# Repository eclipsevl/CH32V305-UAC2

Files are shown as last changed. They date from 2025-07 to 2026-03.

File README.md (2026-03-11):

# CH32V305-UAC2
a usb-hs uac2 dac

> [!NOTE]
> ch32v305fbp6 doesn't have OTG-HS(but it has OTG-FS), so you can't connect this project to a smartphone.  

## hardware v1
ch32v305fbp6 + es9018k2m + opa1678  

## hardware v2
ch32v305fbp6 + es9018k2m + opa1678 + sgm8262  
> [!NOTE]
> you may want to change all the 10uf capacity footprint to 0805, because 0603 10uf may only have 10v version  
> and you may want to add more capacity for charge pump  

## notice

Due to using inexpensive components, the clock has approximately a 200 Hz error. Additionally, the MCLK GPIO speed exceeds the maximum 50 MHz limit at 192 kHz.  
If desired, you can use an external crystal for the I2S MCLK clock.  
This dac only support 48k,96k,192k 32bits, dsd and other formats are not considered.  
This DAC only supports high-speed connections.  
You might hear some popping sounds during sudden high-load tasks. 

## setup
Just flash HSDAC.elf to hardware. Don't use HID-Bootloader and dfu, they will be redoing in future.  

## help wanted
Can someone redesign the power amplifier circuit?  

# IMAGE
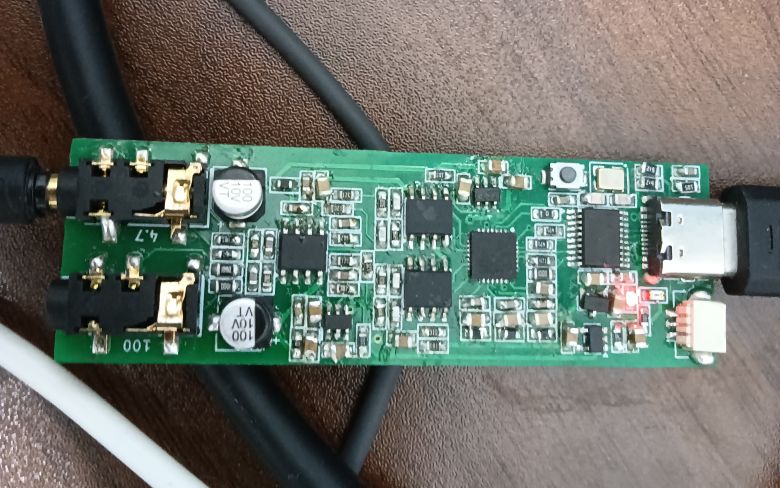
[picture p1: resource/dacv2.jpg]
DAC Image


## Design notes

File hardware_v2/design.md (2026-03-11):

[参考文档](https://www.ti.com.cn/cn/lit/ug/zhcu099/zhcu099.pdf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)  
[ES9018k2m参数](https://item.szlcsc.com/datasheet/ES9018K2M/2794554.html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)

## IV转换器

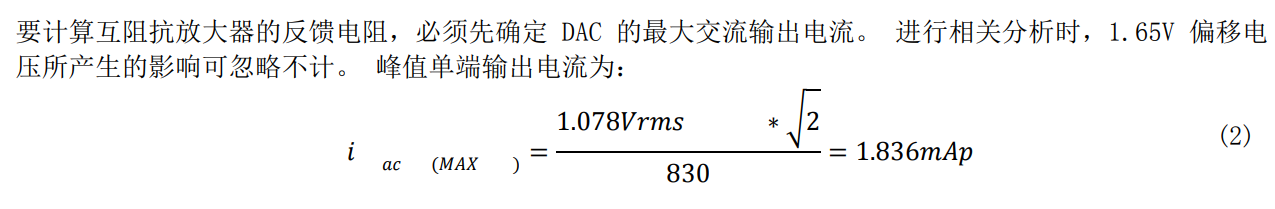
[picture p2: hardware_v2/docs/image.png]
  
es9018k2m峰值输出电流为 3.783/2 = 1.8915mA  

  
opa1678线性电压位于 +-0.8v  

  
我将使用电荷泵产生+-5v，考虑到电压波动，我将运放单个差分通道输出限制在3~4v左右  
因此iv转换器上的反馈电阻最低为 $\frac{3v}/{1.8915mA} = 1586.04om$  
什么几把数字，取个好点的比如2kom  
峰值电压为 2kom * 1.8915mA = 3.783v，离非线性电源柜还有一段距离，可以  
`注：这里电阻越大放大系数越高越有利于减小后级放大的噪声`

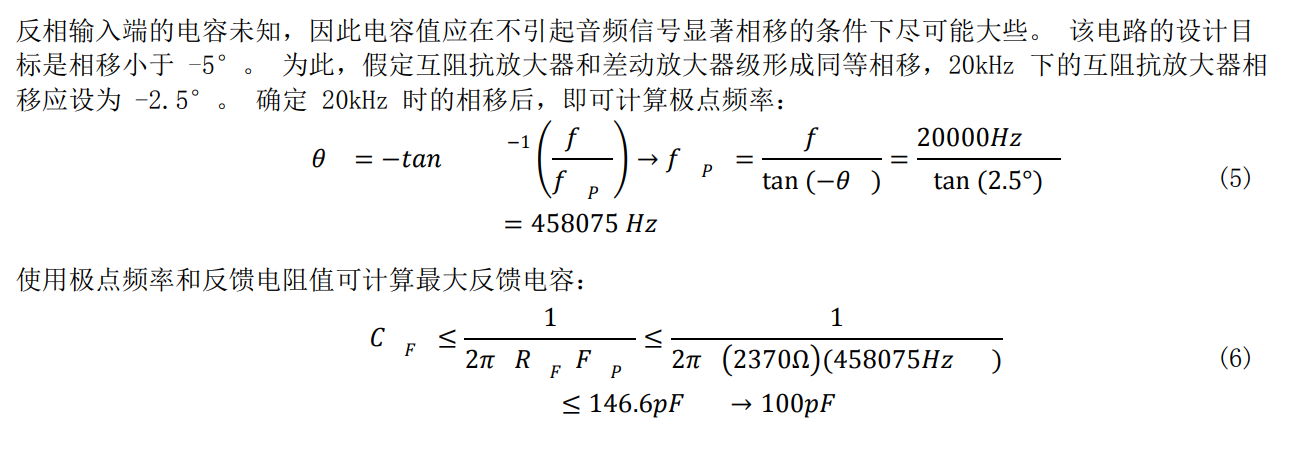
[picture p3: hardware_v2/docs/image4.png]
  
copy一下，计算一下电容为
$$C <= \frac{1}{2\pi(2000)(458075)} = 173.32pF$$

## Vbias

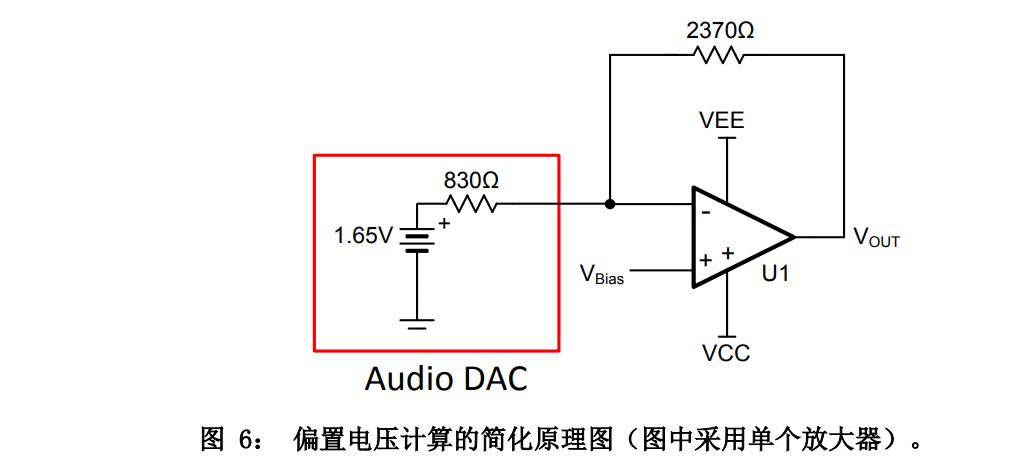
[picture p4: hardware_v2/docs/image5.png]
  
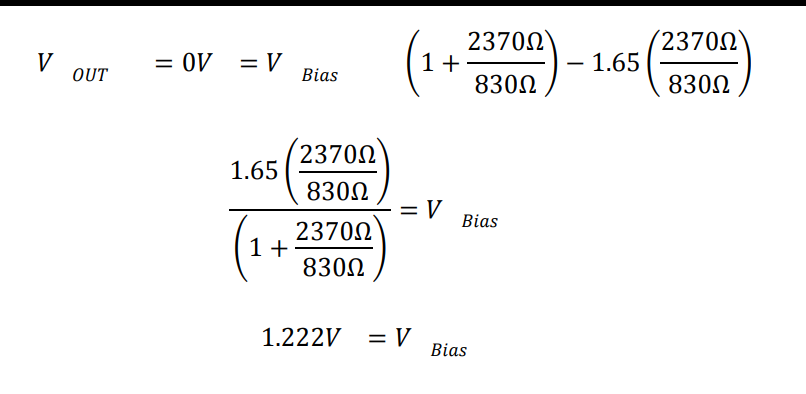
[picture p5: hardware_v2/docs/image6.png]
  
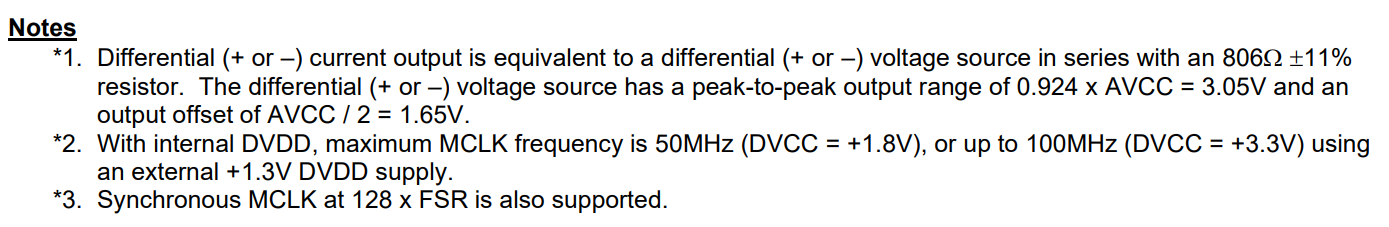
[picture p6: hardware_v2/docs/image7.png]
  
$$Vbais = 1.65*(2000/806) / (1 + 2000/806) = 1.17605132V$$
AI推荐  
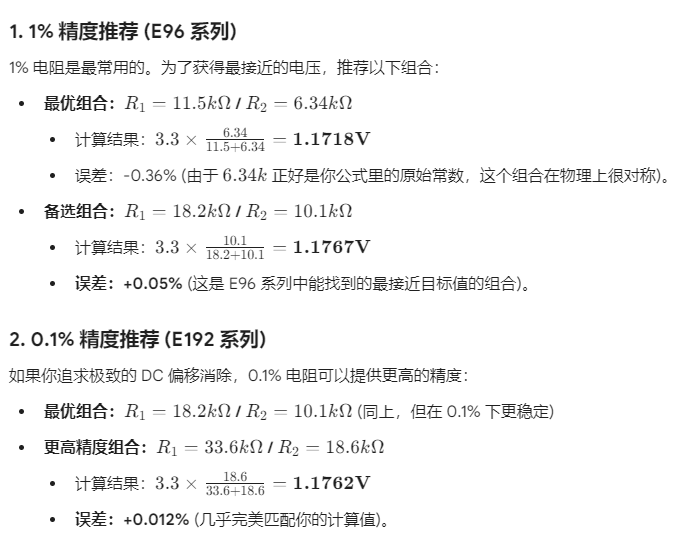
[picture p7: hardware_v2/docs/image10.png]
  
$$C >= \frac{1}{2\pi(R1)||(R2)} = ?$$
第一个是 1.94714318uF  
第二个是 1.225134613uF  
第三个是 0.664673581uF  

## SGM差分放大器

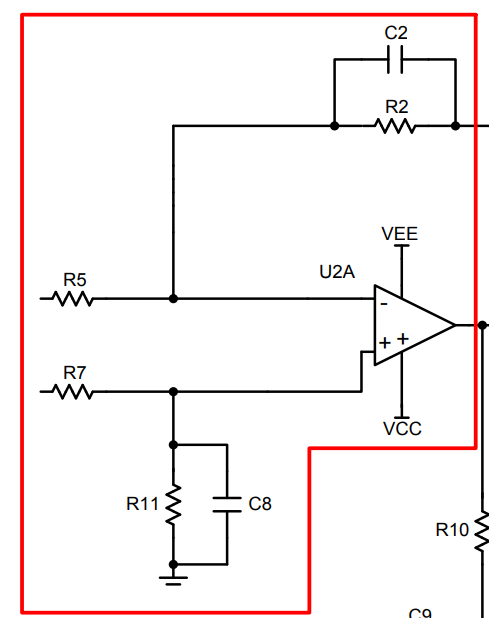
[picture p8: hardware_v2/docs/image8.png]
  
满量程差分放大器输入为 3.783*2 = 7.566v = 5.34996991Vrms  
A = 1.228Vrms / 5.34996991Vrms = 0.229534001  
$$A = \frac{R2}{R5} = \frac{R11}{R7}$$

| 精度级别 | $R_{in}$ (R5, R7) | $R_f$ (R2, R11) | 实际增益 $A$ | 相对误差 | 备注 |
| --- | --- | --- | --- | --- | --- |
| **1% (E96)** | **10.0 kΩ** | **2.32 kΩ** | **0.232** | +1.07% | 最常用、易购组合 |
| **1% (E96)** | **44.2 kΩ** | **10.2 kΩ** | **0.2307** | +0.54% | 阻值稍大，适合降低前级负载 |
| **0.1% (E192)** | **10.0 kΩ** | **2.29 kΩ** | **0.2290** | -0.23% | 非常接近目标值 |
| **0.1% (E192)** | **42.2 kΩ** | **9.65 kΩ** | **0.2286** | -0.37% |  |
| **0.1% (E192)** | **51.1 kΩ** | **11.7 kΩ** | **0.2289** | -0.25% |  |

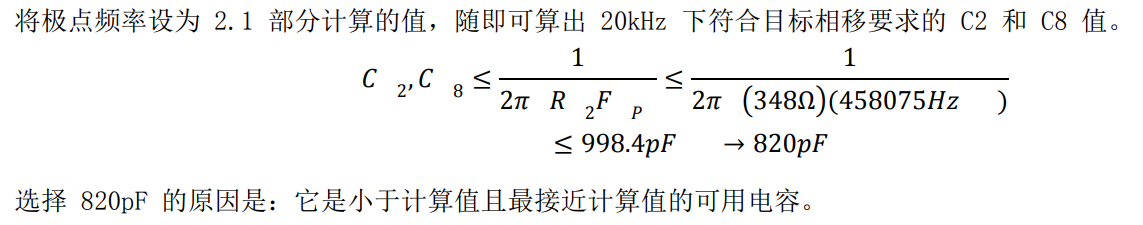
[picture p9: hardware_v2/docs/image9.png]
  
$$C=\frac{1}{2\pi(R2)(458075)} = ?$$

### 1% 精度电阻组合 ($f_c = 458,075\,\text{Hz}$)

| 电阻组合 ($R_{in}$ / $R_f$) | 反馈电阻 $R_f$ | 计算电容值 $C$ | 推荐标准电容值 (皮法) |
| --- | --- | --- | --- |
| **10.0 kΩ / 2.32 kΩ** | $2.32\,\text{k}\Omega$ | $149.7\,\text{pF}$ | **$150\,\text{pF}$** |
| **44.2 kΩ / 10.2 kΩ** | $10.2\,\text{k}\Omega$ | $34.0\,\text{pF}$ | **$33\,\text{pF}$** 或 **$36\,\text{pF}$** |

### 0.1% 精度电阻组合 ($f_c = 458,075\,\text{Hz}$)

| 电阻组合 ($R_{in}$ / $R_f$) | 反馈电阻 $R_f$ | 计算电容值 $C$ | 推荐标准电容值 (皮法) |
| --- | --- | --- | --- |
| **10.0 kΩ / 2.29 kΩ** | $2.29\,\text{k}\Omega$ | $151.7\,\text{pF}$ | **$150\,\text{pF}$** |
| **42.2 kΩ / 9.65 kΩ** | $9.65\,\text{k}\Omega$ | $35.9\,\text{pF}$ | **$36\,\text{pF}$** |
| **51.1 kΩ / 11.7 kΩ** | $11.7\,\text{k}\Omega$ | $29.7\,\text{pF}$ | **$30\,\text{pF}$** |

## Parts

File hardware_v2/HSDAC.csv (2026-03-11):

Reference | Qty | Value | DNP | Exclude from BOM | Exclude from Board | Footprint | Datasheet
C1,C2 | 2 | 12pF |  |  |  | 1My_Footprint:C0603 | ~
C3,C4,C7,C10,C12,C14,C15,C16,C27,C34,C37,C39,C40,C42 | 14 | 10uF |  |  |  | 1My_Footprint:C0603 | ~
C5,C8,C9,C11,C13,C21,C28,C29,C30,C31,C32,C33,C38 | 13 | 100nF |  |  |  | 1My_Footprint:C0603 | ~
C6,C26,C41,C43 | 4 | 2.2uF |  |  |  | 1My_Footprint:C0603 | ~
C17,C18,C19,C20 | 4 | 150pF |  |  |  | 1My_Footprint:C0603 | ~
C22,C23,C24,C25 | 4 | 100pF |  |  |  | 1My_Footprint:C0603 | ~
C35,C36 | 2 | 100uF |  |  |  | Capacitor_SMD:CP_Elec_5x5.4 | ~
D3 | 1 | Power |  |  |  | 1My_Footprint:LED.0603 | ~
F1 | 1 | 500mA |  |  |  | PCM_Fuse_US_Handsoldering_AKL:Fuse_0603_1608Metric | ~
FB1,FB2,FB3,FB4 | 4 | 120R |  |  |  | PCM_Ferrite_SMD_Handsoldering_AKL:Ferrite_0603_1608Metric | ~
IC1 | 1 | ES9018K2M |  |  |  | footprint:QFN50P500X500X90-29N-D | https://www.mouser.com/datasheet/2/1082/ES9018K2M_Datasheet_v3_4-1923459.pdf
J2 | 1 | SWD |  |  |  | Connector_JST:JST_GH_SM03B-GHS-TB_1x03-1MP_P1.25mm_Horizontal | ~
J3 | 1 | USB_C_Receptacle_USB2.0_16P |  |  |  | Connector_USB:USB_C_Receptacle_G-Switch_GT-USB-7010ASV | https://www.usb.org/sites/default/files/documents/usb_type-c.zip
PJ1,PJ2 | 2 | ~ |  |  |  | 1My_Footprint:PJ327A | https://atta.szlcsc.com/upload/public/pdf/source/20240312/2AEB1F200FF9849B98209D1ED7D816C7.pdf
PS1,PS2 | 2 | SGM3204YN6G_TR |  |  |  | footprint:SOT95P280X125-6N | https://datasheet.lcsc.com/szlcsc/SG-Micro-SGM3204YN6G-TR_C194031.pdf
R1,R8,R18,R26,R30,R33 | 6 | 10k |  |  |  | 1My_Footprint:R0603 | ~
R2,R3 | 2 | 5.1k |  |  |  | 1My_Footprint:R0603 | ~
R4,R5,R6 | 3 | 470 |  |  |  | 1My_Footprint:R0603 | ~
R7,R24,R25 | 3 | 100 |  |  |  | 1My_Footprint:R0603 | ~
R9,R11,R20,R21 | 4 | 13k |  |  |  | 1My_Footprint:R0603 | ~
R10,R12,R14,R16 | 4 | 2k |  |  |  | 1My_Footprint:R0603 | ~
R13,R15,R22,R23 | 4 | 3k |  |  |  | 1My_Footprint:R0603 | ~
R17 | 1 | 1M |  |  |  | 1My_Footprint:R0603 | ~
R19,R34 | 2 | 0 |  |  |  | 1My_Footprint:R0603 | ~
R27,R28 | 2 | 4.7k |  |  |  | 1My_Footprint:R0603 | ~
R29 | 1 | 18k |  |  |  | 1My_Footprint:R0603 | ~
R31,R32 | 2 | 4.7 |  |  |  | 1My_Footprint:R0603 | ~
SW1 | 1 | RST |  |  |  | 1My_Footprint:小龟轻触开关3_4_22.0MM | ~
U1 | 1 | CH32V305FBP6 |  |  |  | Package_SO:TSSOP-20_4.4x6.5mm_P0.65mm | http://www.wch-ic.com/products/CH32V307.html?
U2 | 1 | ME6210A33M3G |  |  |  | Package_TO_SOT_SMD:SOT-23 | https://item.szlcsc.com/236120.html
U3,U4 | 2 | OPA1678 |  |  |  | Package_SO:SOIC-8_3.9x4.9mm_P1.27mm | http://www.ti.com/lit/ds/symlink/opa1678.pdf
U5 | 1 | LP5907MFX-3.3 |  |  |  | Package_TO_SOT_SMD:SOT-23-5 | http://www.ti.com/lit/ds/symlink/lp5907.pdf
U7 | 1 | sgm8262 |  |  |  | Package_SO:SOIC-8_3.9x4.9mm_P1.27mm | https://item.szlcsc.com/datasheet/SGM8262-2YS8G%252FTR/5778896.html
X1 | 1 | 8M |  |  |  | PCM_Crystal_AKL:Crystal_SMD_3225-4Pin_3.2x2.5mm | ~

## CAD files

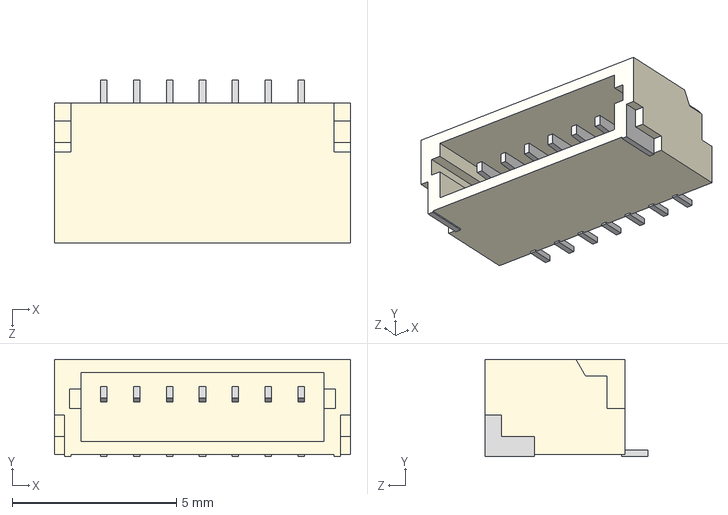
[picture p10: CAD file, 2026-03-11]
hardware_v2/3rd/3d/SM07B-SRSS-TB_LF__SN_.stp
9.00 x 2.96 x 4.95 mm

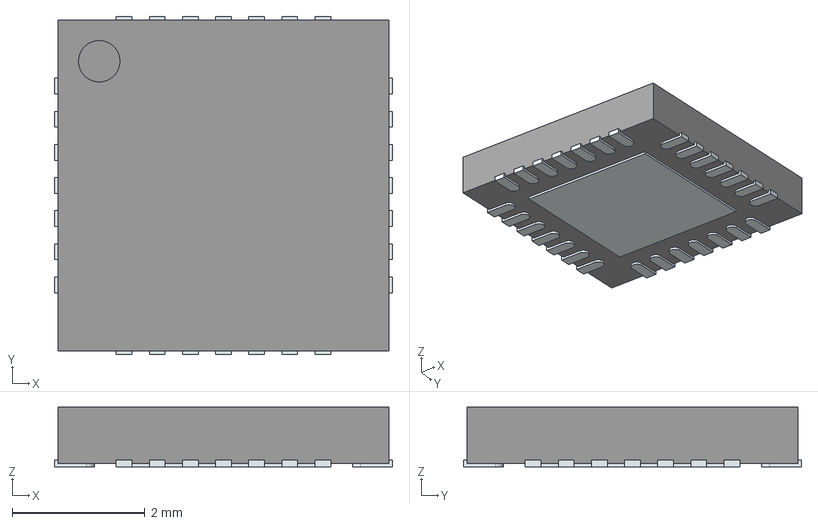
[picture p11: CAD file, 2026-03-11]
hardware_v2/3rd/3d/ES9018K2M.stp
5.10 x 5.10 x 0.9 mm
ThermalPin
PinsArrayLR
PinsArrayTB

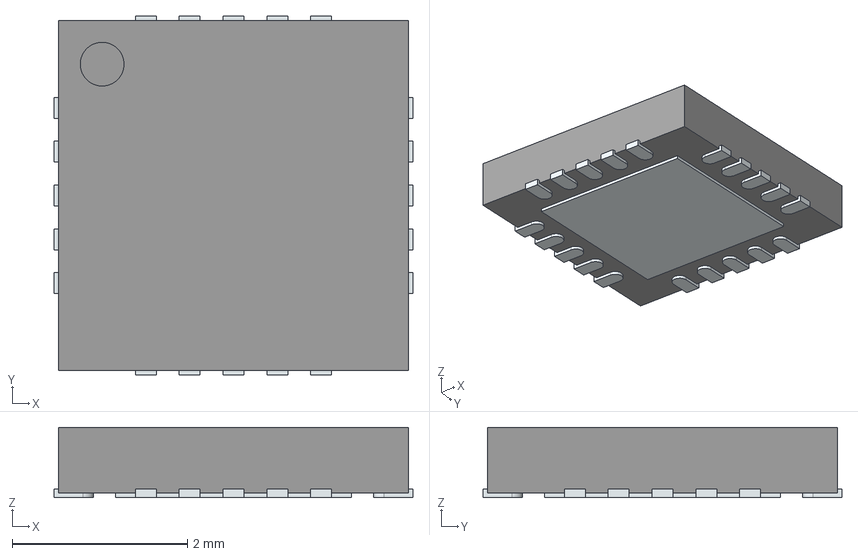
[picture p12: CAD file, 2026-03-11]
hardware_v2/3rd/3d/TPA6130A2RTJR.stp
4.10 x 4.10 x 0.8 mm
ThermalPin
PinsArrayLR
PinsArrayTB

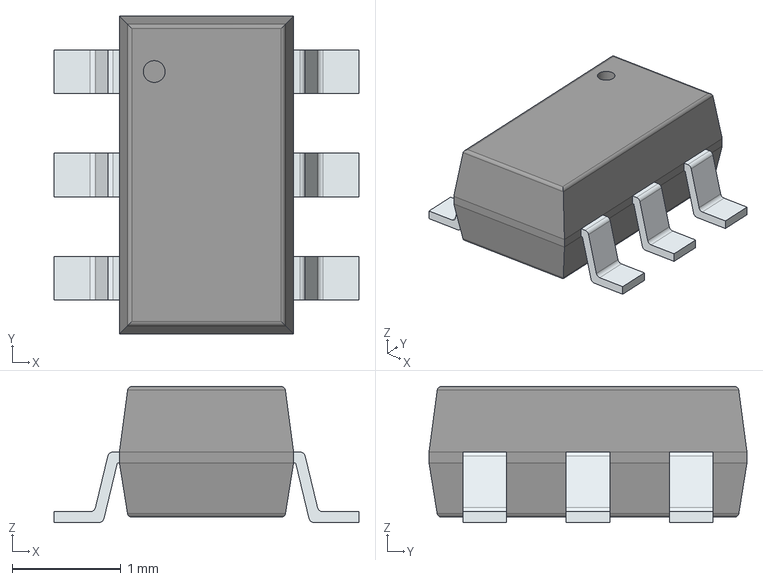
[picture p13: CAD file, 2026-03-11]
hardware_v2/3rd/3d/SGM3204YN6G_TR.stp
2.80 x 2.92 x 1.25 mm
PinsArrayLR

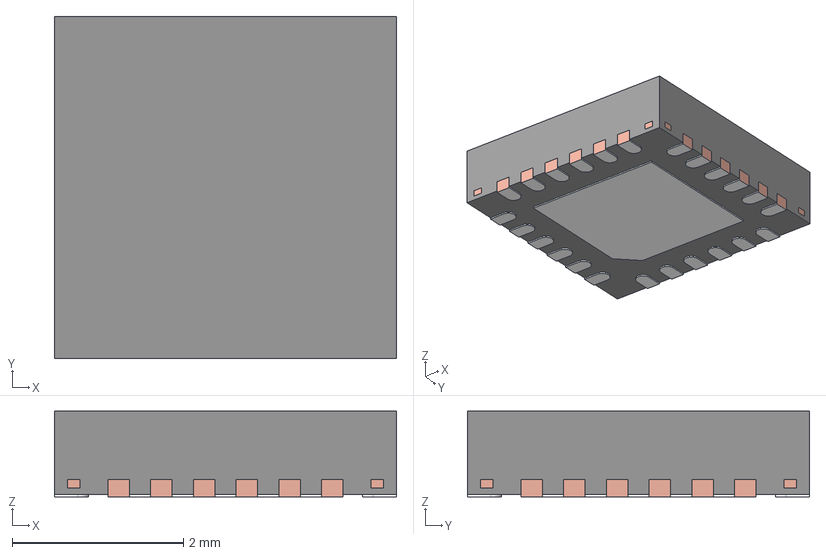
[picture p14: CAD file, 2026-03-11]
hardware_v2/3rd/3d/TPS65131RGER.stp
4.00 x 4.00 x 1.00 mm
BODY-QFN
FRAME-RGE0024B
PIN1-ID

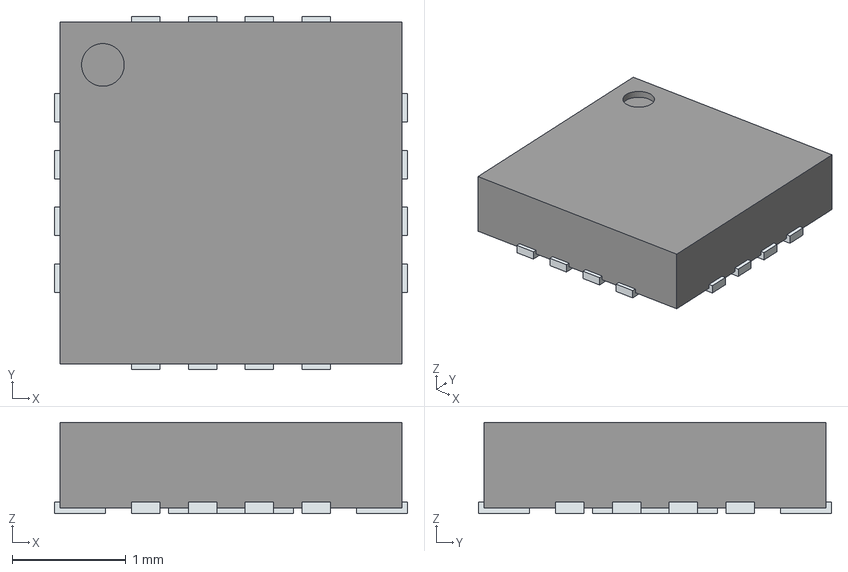
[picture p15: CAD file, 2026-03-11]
hardware_v2/3rd/3d/MAX97220AETE+T.stp
3.10 x 3.10 x 0.8 mm
ThermalPin
PinsArrayLR
PinsArrayTB

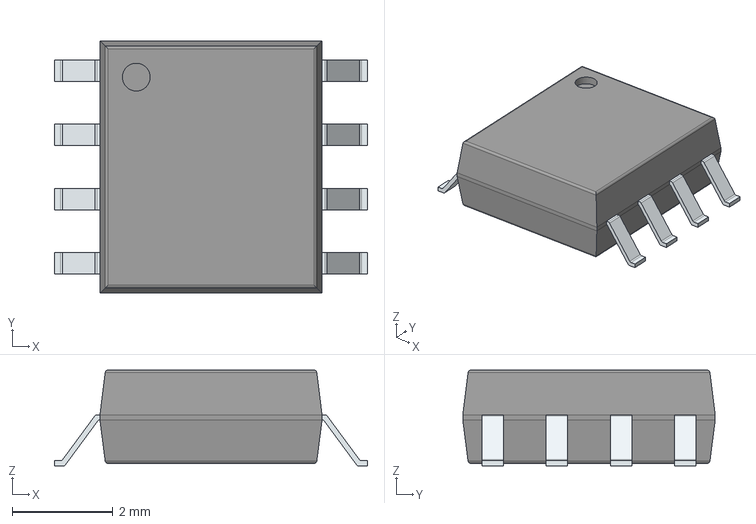
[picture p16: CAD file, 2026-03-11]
hardware_v2/3rd/3d/M62429FP.stp
6.20 x 5.00 x 1.90 mm
PinsArrayLR

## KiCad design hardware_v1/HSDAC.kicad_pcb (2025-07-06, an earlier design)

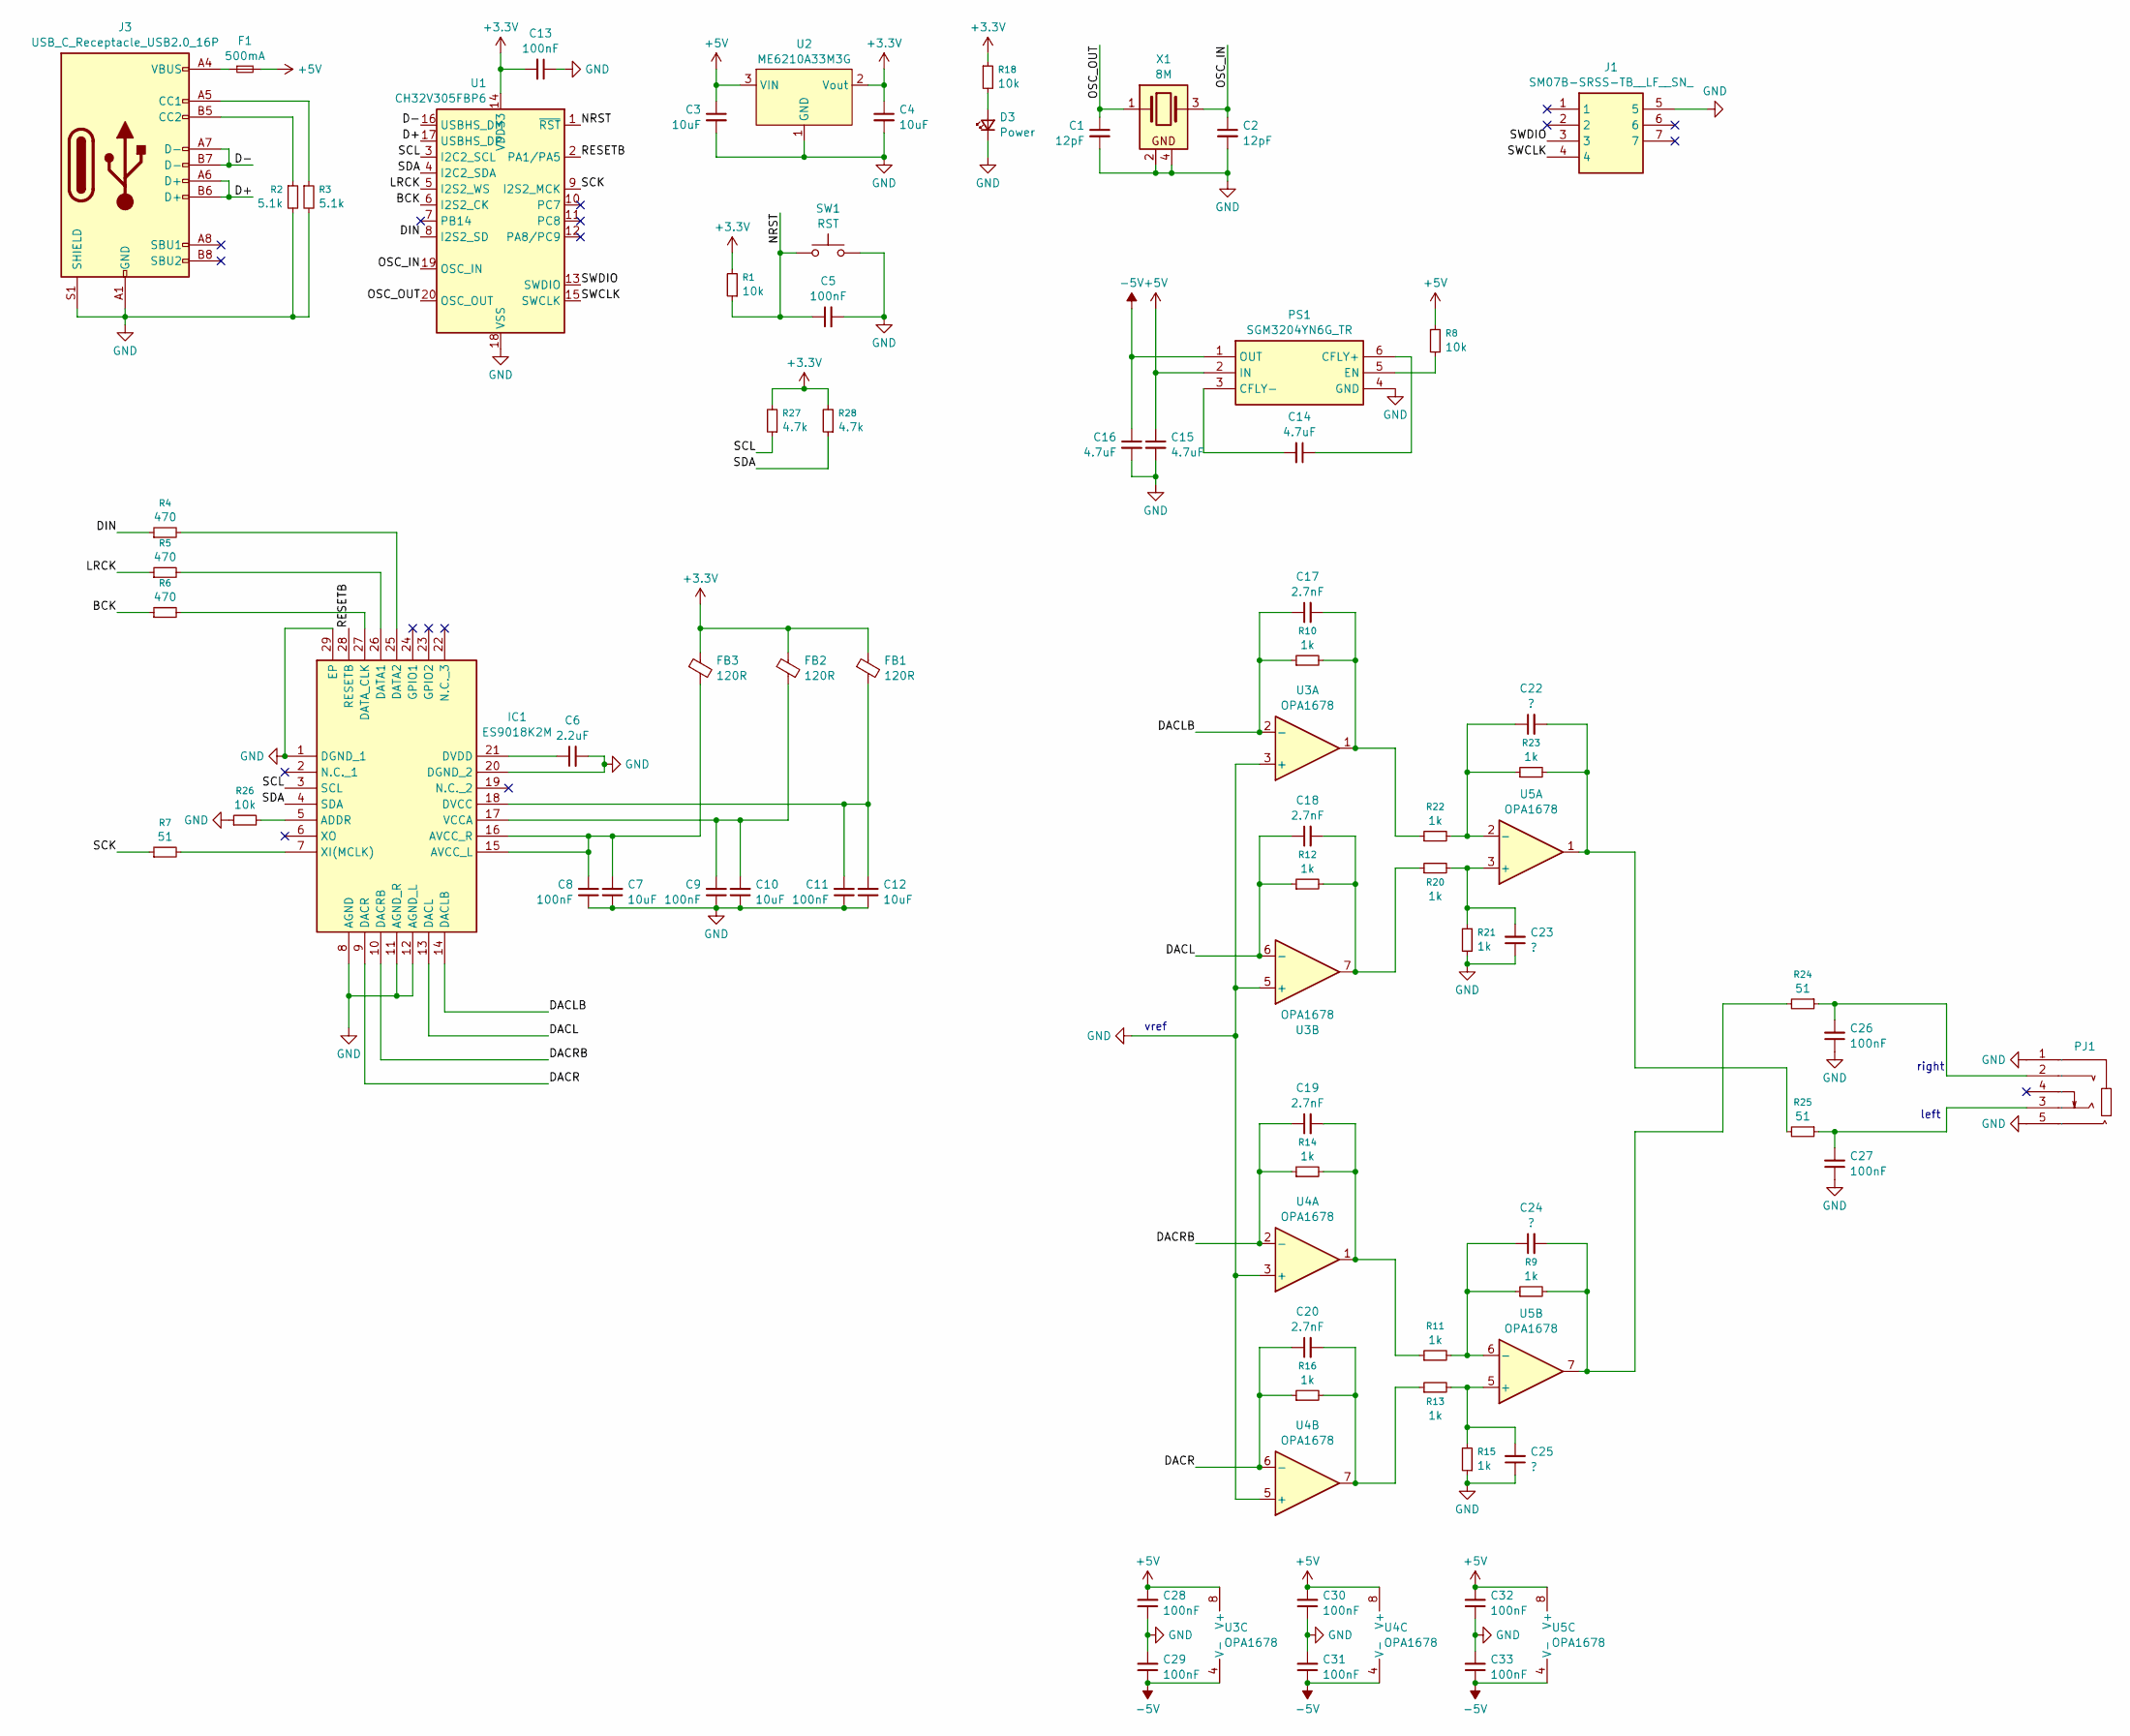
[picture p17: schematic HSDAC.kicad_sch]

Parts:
C1, C2: 12pF; C_0603_1608Metric_Pad1.05x0.95mm_HandSolder
C3, C4, C7, C10, C12: 10uF; C_0603_1608Metric_Pad1.05x0.95mm_HandSolder
C5, C8, C9, C11, C13, C26, C27, C28, C29, C30, C31, C32, C33: 100nF; C_0603_1608Metric_Pad1.05x0.95mm_HandSolder
C6: 2.2uF; C_0603_1608Metric_Pad1.05x0.95mm_HandSolder
C14, C15, C16: 4.7uF; C_0603_1608Metric_Pad1.05x0.95mm_HandSolder
C17, C18, C19, C20: 2.7nF; C_0603_1608Metric_Pad1.05x0.95mm_HandSolder
C22, C23, C24, C25: ?; C_0603_1608Metric_Pad1.05x0.95mm_HandSolder
D3: Power; LED_0805_2012Metric
F1: 500mA; Fuse_0603_1608Metric
FB1, FB2, FB3: 120R; Ferrite_0603_1608Metric
IC1: ES9018K2M; QFN50P500X500X90-29N-D; Manufacturer_Part_Number ES9018K2M; Mouser Part Number 460-ES9018K2M
J1: SM07B-SRSS-TB__LF__SN_; SM07B-SRSS-TB; Manufacturer_Part_Number SM07B-SRSS-TB (LF)(SN)
J3: USB_C_Receptacle_USB2.0_16P; USB_C_Receptacle_G-Switch_GT-USB-7010ASV
PJ1: AUDIO-IN-SMD_PJ-327A_C22355751; Manufacturer Part PJ-327A; LCSC Part Name PJ-327A
PS1: SGM3204YN6G_TR; SOT95P280X125-6N; Manufacturer_Part_Number SGM3204YN6G/TR
R1, R8, R18, R26: 10k; R_0603_1608Metric_Pad0.98x0.95mm_HandSolder
R2, R3: 5.1k; R_0603_1608Metric_Pad0.98x0.95mm_HandSolder
R4, R5, R6: 470; R_0603_1608Metric_Pad0.98x0.95mm_HandSolder
R7, R24, R25: 51; R_0603_1608Metric_Pad0.98x0.95mm_HandSolder
R9, R10, R11, R12, R13, R14, R15, R16, R20, R21, R22, R23: 1k; R_0603_1608Metric_Pad0.98x0.95mm_HandSolder
R27, R28: 4.7k; R_0603_1608Metric_Pad0.98x0.95mm_HandSolder
SW1: RST; SW-SMD_L4.0-W3.0-LS4.8-1
U1: CH32V305FBP6; TSSOP-20_4.4x6.5mm_P0.65mm
U2: ME6210A33M3G; SOT-23
U3, U4, U5: OPA1678; SOIC-8_3.9x4.9mm_P1.27mm
X1: 8M; Crystal_SMD_3225-4Pin_3.2x2.5mm

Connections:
+3.3V: C4.1, C13.2, FB1.1, FB2.1, FB3.1, R1.2, R18.1, R27.2, R28.2, U1.14 (VDD33), U2.2 (Vout)
+5V: C3.1, C15.1, C28.2, C30.2, C32.2, F1.2, PS1.2 (IN), R8.2, U2.3 (VIN), U3.8 (V+), U4.8 (V+), U5.8 (V+)
-5V: C16.1, C29.1, C31.1, C33.1, PS1.1 (OUT), U3.4 (V-), U4.4 (V-), U5.4 (V-)
/BCK: R6.1, U1.6 (I2S2_CK)
/D+: J3.A6 (D+), J3.B6 (D+), U1.17 (USBHS_DP)
/D-: J3.A7 (D-), J3.B7 (D-), U1.16 (USBHS_DM)
/DACL: C18.1, IC1.13 (DACL), R12.1, U3.6 (-)
/DACLB: C17.1, IC1.14 (DACLB), R10.1, U3.2 (-)
/DACR: C20.1, IC1.9 (DACR), R16.1, U4.6 (-)
/DACRB: C19.1, IC1.10 (DACRB), R14.1, U4.2 (-)
/DIN: R4.1, U1.8 (I2S2_SD)
/LRCK: R5.1, U1.5 (I2S2_WS)
/NRST: C5.1, R1.1, SW1.1, U1.1 (~RST)
/OSC_IN: C2.1, U1.19 (OSC_IN), X1.3
/OSC_OUT: C1.1, U1.20 (OSC_OUT), X1.1
/RESETB: IC1.28 (RESETB), U1.2 (PA1/PA5)
/SCK: R7.1, U1.9 (I2S2_MCK)
/SCL: IC1.3 (SCL), R27.1, U1.3 (I2C2_SCL)
/SDA: IC1.4 (SDA), R28.1, U1.4 (I2C2_SDA)
/SWCLK: J1.4, U1.15 (SWCLK)
/SWDIO: J1.3, U1.13 (SWDIO)
GND: C1.2, C2.2, C3.2, C4.2, C5.2, C6.2, C7.1, C8.1, C9.1, C10.1, C11.1, C12.1, C13.1, C15.2, C16.2, C23.1, C25.1, C26.1, C27.1, C28.1, C29.2, C30.1, C31.2, C32.1, C33.2, D3.1 (K), IC1.1 (DGND_1), IC1.8 (AGND), IC1.11 (AGND_R), IC1.12 (AGND_L), IC1.20 (DGND_2), IC1.29 (EP), J1.5, J3.A1 (GND), J3.A12 (GND), J3.B1 (GND), J3.B12 (GND), J3.S1 (SHIELD), PJ1.1, PJ1.5, PS1.4 (GND), R2.2, R3.2, R15.1, R21.1, R26.1, SW1.2, U1.18 (VSS), U2.1 (GND), U3.3 (+), U3.5 (+), U4.3 (+), U4.5 (+), X1.2, X1.4
unnamed: C17.2, R10.2, R22.1, U3.1
unnamed: C18.2, R12.2, R20.1, U3.7
unnamed: C19.2, R11.1, R14.2, U4.1
unnamed: C20.2, R13.1, R16.2, U4.7
unnamed: C22.2, R23.2, R25.2, U5.1
unnamed: C24.2, R9.2, R24.2, U5.7
unnamed: C26.2, PJ1.2, R24.1
unnamed: C27.2, PJ1.3, R25.1
unnamed: D3.2 (A), R18.2
unnamed: F1.1, J3.A4 (VBUS), J3.A9 (VBUS), J3.B4 (VBUS), J3.B9 (VBUS)
unnamed: IC1.5 (ADDR), R26.2
unnamed: C7.2, C8.2, FB3.2, IC1.15 (AVCC_L), IC1.16 (AVCC_R)
unnamed: IC1.26 (DATA1), R5.2
unnamed: IC1.25 (DATA2), R4.2
unnamed: IC1.27 (DATA_CLK), R6.2
unnamed: C11.2, C12.2, FB1.2, IC1.18 (DVCC)
unnamed: C6.1, IC1.21 (DVDD)
unnamed: C9.2, C10.2, FB2.2, IC1.17 (VCCA)
unnamed: IC1.7 (XI(MCLK)), R7.2
unnamed: J3.A5 (CC1), R3.1
unnamed: J3.B5 (CC2), R2.1
unnamed: C14.1, PS1.6 (CFLY+)
unnamed: C14.2, PS1.3 (CFLY-)
unnamed: PS1.5 (EN), R8.1
unnamed: C23.2, R20.2, R21.2, U5.3 (+)
unnamed: C22.1, R22.2, R23.1, U5.2 (-)
unnamed: C25.2, R13.2, R15.2, U5.5 (+)
unnamed: C24.1, R9.1, R11.2, U5.6 (-)

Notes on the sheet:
right
left
vref

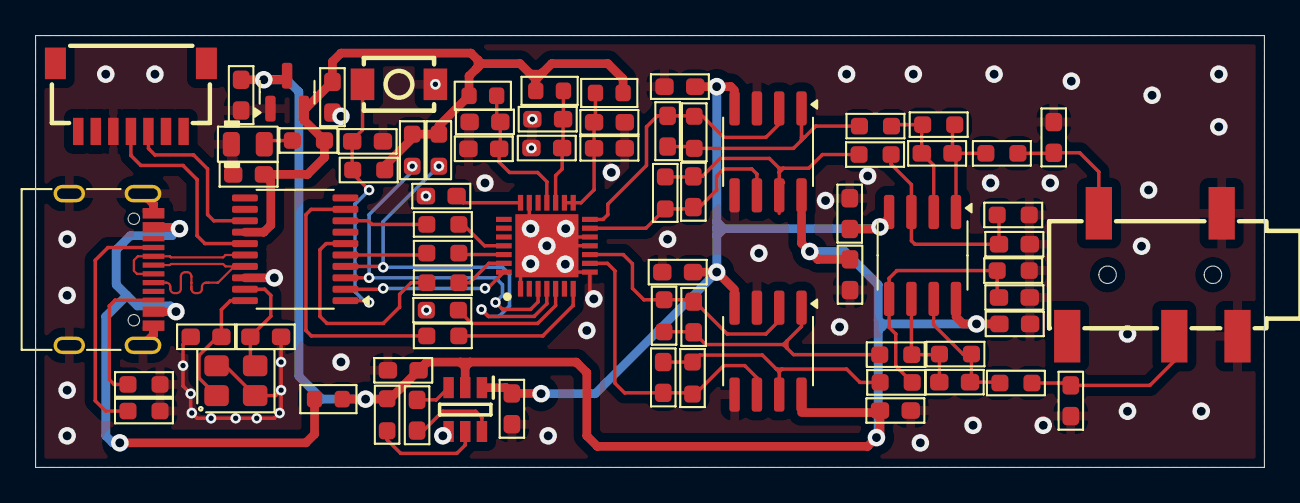
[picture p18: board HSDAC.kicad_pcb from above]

Board: 2 copper layers, 70.0 x 24.6 mm, 75 parts (0 on the bottom side), 50 nets.

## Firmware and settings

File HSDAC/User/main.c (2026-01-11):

#include "ch32v30x_misc.h"
#include "debug.h"
#include "tick.h"
#include "usbd.h"
#include "codec.h"
#include "audio_block.h"
#include "codec_i2s.h"

int main(void) {
    NVIC_PriorityGroupConfig(NVIC_PriorityGroup_2);
    SystemCoreClockUpdate();
    Delay_Init();
    Tick_Init();
    Usbd_Init();
    bool inited = Codec_Init();

    Usbd_Connect();
    uint32_t tick = Tick_GetTick();
    for (;;) {
        Codec_Handler();
        AudioBlock_Handler();

        uint32_t now = Tick_GetTick();
        if (now - tick > 1000) {
            if (!inited) {
                printf("codec inited failed\n\r");
            }
            tick = now;

            printf("codec dma have %ld\n\r", CodecI2s_GetFreeSpace());
        }
    }

    return 0;
}

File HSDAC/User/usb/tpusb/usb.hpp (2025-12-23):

#pragma once
#include <array>
#include <cstddef>
#include <type_traits>
#include <cstdint>

namespace tpusb {

// --------------------------------------------------------------------------------
// STANDARD USB
// --------------------------------------------------------------------------------

#pragma GCC diagnostic push
#pragma GCC diagnostic ignored "-Wpragmas"
#pragma GCC diagnostic ignored "-Winvalid-constexpr"
static constexpr int TriggerConstexprError(const char*) {
    volatile int x = 10;
    // error: 'x' is a volatile-qualified glvalue
    return x;
}
#pragma GCC diagnostic pop

// ----------------------------------------
// CharArray
// ----------------------------------------

/**
 * @brief 一个在编译期拼接的uint8数组，用于USB描述
 * 
 * @tparam N 
 */
template<size_t N>
struct CharArray {
    static constexpr size_t desc_len = N;
    uint8_t desc[N]{};
    
    constexpr uint8_t& operator[](size_t i) {
        return desc[i];
    }

    constexpr uint8_t operator[](size_t i) const {
        return desc[i];
    }

    template<size_t N2, size_t N3>
    constexpr void MergeArray(const CharArray<N2>& lh, const CharArray<N3>& rh) {
        for (size_t i = 0; i < N2; ++i) {
            desc[i] = lh[i];
        }
        for (size_t i = 0; i < N3; ++i) {
            desc[i + N2] = rh[i];
        }
    }

    template<size_t N2>
    constexpr size_t Copy(size_t this_offset, const CharArray<N2>& other) {
        for (size_t i = 0; i < N2; ++i) {
            desc[this_offset + i] = other.desc[i];
        }
        return this_offset + N2;
    }
};

/**
 * @brief 获取描述结构体的CharArray的长度
 * 
 * @tparam DESC 
 */
template<class DESC>
static constexpr size_t desc_len = DESC::len;

/**
 * @brief 获取整个描述的长度
 * 
 * @tparam DESC 
 */
template<class...DESC>
struct DESC_LEN_SUMMER {
    static constexpr size_t len = (0 + ... + desc_len<DESC>);
};

// ----------------------------------------
// USB Endpoint
// ----------------------------------------

/**
 * @brief USB块传输端点描述
 * 
 */
struct BulkInitPack {
    uint8_t address;
    uint16_t max_pack_size;
    uint8_t interval;
};

/**
 * @brief 似乎是旧版的USB块传输端点描述
 * 
 */
struct BulkInitPackLen9 {
    uint8_t address;
    uint16_t max_pack_size;
    uint8_t interval;
    uint8_t refresh;
    uint8_t sync_address;
};

/**
 * @brief USB中断传输端点描述
 * 
 */
struct InterruptInitPack {
    uint8_t address;
    uint16_t max_pack_size;
    uint8_t interval;
};

/**
 * @brief 旧版USB中断传输端点描述
 * 
 */
struct InterruptInitPackLen9 {
    uint8_t address;
    uint16_t max_pack_size;
    uint8_t interval;
    uint8_t refresh;
    uint8_t sync_address;
};

/**
 * @brief USB同步传输同步类型
 * 
 */
enum class SynchronousType {
    None,
    Isochronous,
    Adaptive,
    Synchronous
};

/**
 * @brief USB同步传输同步方式
 * 
 */
enum class IsoEpType {
    Data,
    Feedback,
    ImplicitFeedback
};

/**
 * @brief USB同步传输端点描述
 * 
 */
struct IsochronousInitPack {
    uint8_t address;
    uint16_t max_pack_size;
    uint8_t interval;
    SynchronousType sync_type;
    IsoEpType endpoint_type;
};

/**
 * @brief 旧版USB同步传输端点描述
 * 
 */
struct IsochronousInitPackLen9 {
    uint8_t address;
    uint16_t max_pack_size;
    uint8_t interval;
    SynchronousType sync_type;
    IsoEpType endpoint_type;
    uint8_t refresh;
    uint8_t sync_address;
};

/**
 * @brief USB控制传输端点描述
 * 
 */
struct ControlInitPack {
    uint8_t address;
    uint16_t max_pack_size;
    uint8_t interval;
};

/**
 * @brief 旧版USB控制传输端点描述
 * 
 */
struct ControlInitPackLen9 {
    uint8_t address;
    uint16_t max_pack_size;
    uint8_t interval;
    uint8_t refresh;
    uint8_t sync_address;
};

/**
 * @brief USB端点接口
 * 
 */
struct IEndpoint {
    static constexpr size_t len_offset = 0;
    static constexpr size_t desc_type_offset = 1;
    static constexpr size_t address_offset = 2;
    static constexpr size_t attribute_offset = 3;
    static constexpr size_t max_pack_low_offset = 4;
    static constexpr size_t max_pack_high_offset = 5;
    static constexpr size_t interval_offset = 6;
    static constexpr size_t refresh_offset = 7;
    static constexpr size_t sync_address_offset = 8;
};
template<class... DESCS>
struct Endpoint : public IEndpoint {
    static constexpr size_t len = DESC_LEN_SUMMER<DESCS...>::len + 7;
    CharArray<len> char_array {
        7,
        5,
    };
    size_t begin = 7;

    constexpr Endpoint(BulkInitPack pack, const DESCS&... decs) {
        char_array[2] = pack.address;
        char_array[3] = 0x02;
        char_array[4] = pack.max_pack_size & 0xff;
        char_array[5] = pack.max_pack_size >> 8;
        char_array[6] = pack.interval;
        (AppendDesc(decs),...);
    }

    constexpr Endpoint(InterruptInitPack pack, const DESCS&... decs) {
        char_array[2] = pack.address;
        char_array[3] = 0x03;
        char_array[4] = pack.max_pack_size & 0xff;
        char_array[5] = pack.max_pack_size >> 8;
        char_array[6] = pack.interval;
        (AppendDesc(decs),...);
    }

    constexpr Endpoint(IsochronousInitPack pack, const DESCS&... decs) {
        char_array[2] = pack.address;
        char_array[3] = 0x01 | (static_cast<uint8_t>(pack.sync_type) << 2) | (static_cast<uint8_t>(pack.endpoint_type) << 4);
        char_array[4] = pack.max_pack_size & 0xff;
        char_array[5] = pack.max_pack_size >> 8;
        char_array[6] = pack.interval;
        (AppendDesc(decs),...);
    }

    constexpr Endpoint(ControlInitPack pack, const DESCS&... decs) {
        char_array[2] = pack.address;
        char_array[3] = 0;
        char_array[4] = pack.max_pack_size & 0xff;
        char_array[5] = pack.max_pack_size >> 8;
        char_array[6] = pack.interval;
        (AppendDesc(decs),...);
    }

    template<class DESC>
    constexpr void AppendDesc(const DESC& desc) {
        size_t desc_len = desc.len;
        for (size_t i = 0; i < desc_len ; ++i) {
            char_array[begin + i] = desc.char_array[i];
        }
        begin += desc_len;
    }
};
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

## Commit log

2025-07-06 fix exception when upload firmware
    [HSDAC.kicad_pcb]
2025-12-23 set es9018 using interrupt
2026-01-11 remove slience detect module feat: add ability to process audio in main thread
2026-03-11 add hardware v2
    [BOM-HSDAC.csv, ES9018K2M.stp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]
